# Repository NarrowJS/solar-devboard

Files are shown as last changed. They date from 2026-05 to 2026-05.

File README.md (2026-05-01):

## Solar Devboard
An ESP32 C6 mini based devboard that combines zigbee/wifi with solar and lipo charging to easily deploy remote sensing IOT devices.

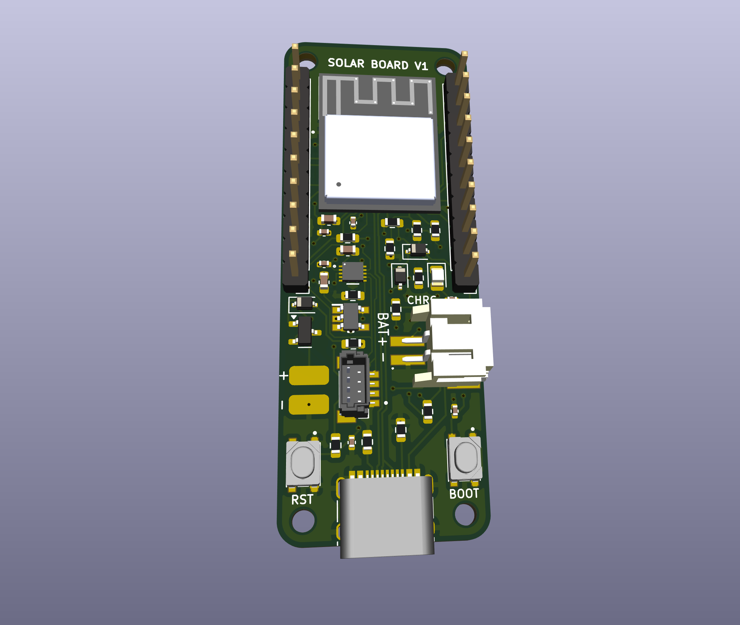
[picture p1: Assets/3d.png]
3d model

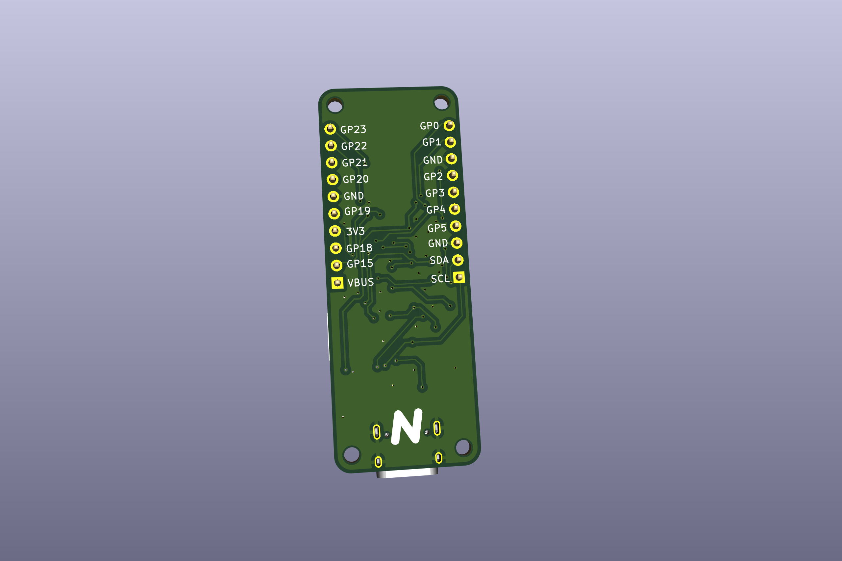
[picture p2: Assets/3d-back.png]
3d model back

## Features
- 3.7v Lipo charging circuit and JST connector
- Support for 3v - 18v solar panels
- Reverse polarity protection on solar panel connector
- ADC for lipo charge monitoring
- Power path for charging while on usb-c power
- Extremely compact form factor
- M2 mounting holes

## Why
- Solar panels are extremely useful for remote sensing applications to provide a power source without long wires or very large batteries
- Most solar projects require boost converters and extra breakout boards to connect lipo batteries safely
- Most solar charging boards are too large to be used in compact applications

## BOM
| Reference | Value | Datasheet | Footprint | Qty | DNP | Link |
|---|---|---|---|-----|-----|---|
| C1,C2,C4,C5,C10 | 100nF | ~ | Capacitor_SMD:C_0402_1005Metric | 5 | | https://www.lcsc.com/product-detail/C60474.html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 |
| C3,C6,C12 | 10uF | ~ | Capacitor_SMD:C_0603_1608Metric | 3 | | https://www.lcsc.com/product-detail/C19702.html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 |
| C7 | 1uF | ~ | Capacitor_SMD:C_0402_1005Metric | 1 | | https://www.lcsc.com/product-detail/C19702.html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 |
| D1 | CHARGE LED | ~ | LED_SMD:LED_0805_2012Metric | 1 | | https://www.lcsc.com/product-detail/C19702.html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 |
| D2,D3,D4 | 1N5819WS | https://datasheet.lcsc.com/lcsc/2204281430_Guangdong-Hottech-1N5819WS_C191023.pdf | Diode_SMD:D_SOD-323 | 3 | | https://www.lcsc.com/product-detail/C191023.html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 |
| IC1 | RT9080-33GJ5 | | RT9080-33GJ5:SOT94P280X100-5N | 1 | | https://www.lcsc.com/product-detail/C191023.html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 |
| J1 | USB_C_Receptacle_USB2.0_14P | https://www.usb.org/sites/default/files/documents/usb_type-c.zip | Connector_USB:USB_C_Receptacle_HRO_TYPE-C-31-M-12 | 1 | | https://www.lcsc.com/product-detail/C165948.html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 |
| J2 | SOLAR_IN + | ~ | Connector_Wire:SolderWirePad_1x01_SMD_1x2mm | 1 | | |
| J3 | SOLAR_IN - | ~ | Connector_Wire:SolderWirePad_1x01_SMD_1x2mm | 1 | | |
| J4,J5 | Conn_01x10_Pin | ~ | Connector_PinHeader_2.54mm:PinHeader_1x10_P2.54mm_Vertical | 2 | | https://www.lcsc.com/product-detail/C42431810.html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 |
| J6 | 4328 | | 4328:ADAFRUIT_4328 | 1 | | https://www.adafruit.com/product/4328 |
| P1 | S2B-PH-SM4-TB | | S2B-PH-SM4-TB:JST_S2B-PH-SM4-TB | 1 | | https://www.lcsc.com/product-detail/C295747.html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 |
| Q2 | AO3401A | http://www.aosmd.com/pdfs/datasheet/AO3401A.pdf | Package_TO_SOT_SMD:SOT-23 | 1 | | https://www.lcsc.com/product-detail/C15127.html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 |
| R1,R2 | 5k1 | ~ | Resistor_SMD:R_0603_1608Metric | 2 | | https://www.lcsc.com/product-detail/C15127.html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 |
| R3,R4,R5,R6,R8,R9,R10 | 10k | ~ | Resistor_SMD:R_0603_1608Metric | 7 | | https://www.lcsc.com/product-detail/C98220.html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 |
| R7 | 1k | ~ | Resistor_SMD:R_0603_1608Metric | 1 | | https://www.lcsc.com/product-detail/C2907002.html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 |
| R11 | 27k | ~ | Resistor_SMD:R_0603_1608Metric | 1 | | https://www.lcsc.com/product-detail/C22967.html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 |
| R12,R15 | 100k | ~ | Resistor_SMD:R_0603_1608Metric | 2 | | https://www.lcsc.com/product-detail/C14675.html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 |
| SW1,SW2 | PTS810_SJM_250_SMTR_LFS | | PTS810_SJM_250_SMTR_LFS:SW_PTS810_SJM_250_SMTR_LFS | 2 | | https://www.lcsc.com/product-detail/C116501.html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 |
| U1 | ESP32-C6-MINI-1-H4 | | ESP32-C6-MINI-1-H4:XCVR_ESP32-C6-MINI-1-H4 | 1 | | https://www.lcsc.com/product-detail/C5736265.html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 |
| U2 | PQ25186DLHR | https://www.ti.com/lit/gpn/bq25186 | BQ25186:WSON10_DLH_TEX | 1 | | https://www.lcsc.com/product-detail/C44639442.html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 |

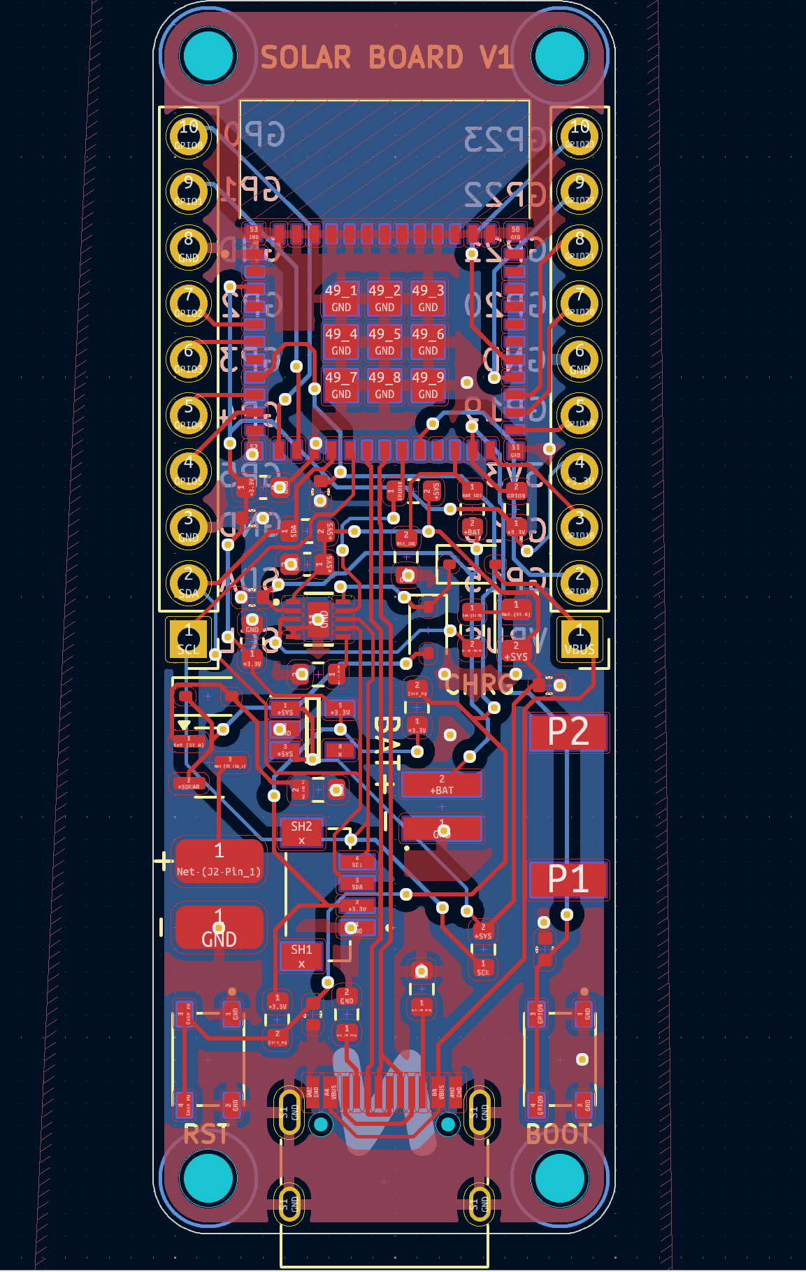
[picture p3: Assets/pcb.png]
pcb

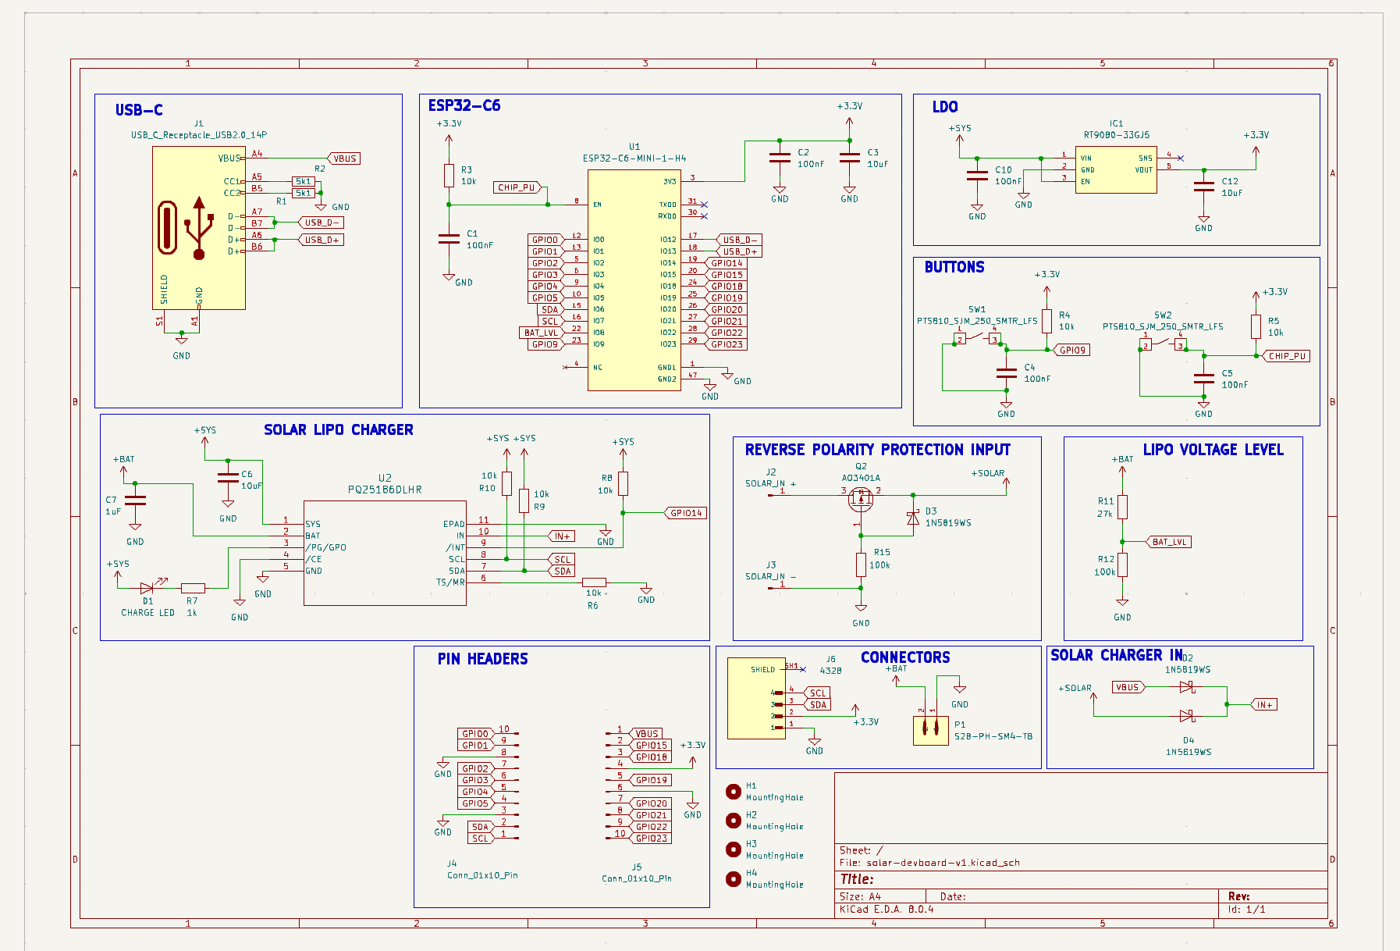
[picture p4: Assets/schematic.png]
schematic


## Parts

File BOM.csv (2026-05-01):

Reference | Value | Datasheet | Footprint | Qty | DNP | Link | total cost
C1,C2,C4,C5,C10 | 100nF | ~ | Capacitor_SMD:C_0402_1005Metric | 5 |  | https://www.lcsc.com/product-detail/C60474.html?s_z=n_q_100nF%25200402 | 0.11
C3,C6,C12 | 10uF | ~ | Capacitor_SMD:C_0603_1608Metric | 3 |  | https://www.lcsc.com/product-detail/C19702.html?s_z=n_q_10uF%25200603 | 0.4
C7 | 1uF | ~ | Capacitor_SMD:C_0402_1005Metric | 1 |  | https://www.lcsc.com/product-detail/C19702.html?s_z=n_q_10uF%25200603 | 0.28
D1 | CHARGE LED | ~ | LED_SMD:LED_0805_2012Metric | 1 |  | https://www.lcsc.com/product-detail/C19171391.html?s_z=n_q_red%2520led%2520smd%25200805 | 0.81
D2,D3,D4 | 1N5819WS | https://datasheet.lcsc.com/lcsc/2204281430_Guangdong-Hottech-1N5819WS_C191023.pdf | Diode_SMD:D_SOD-323 | 3 |  | https://www.lcsc.com/product-detail/C191023.html?s_z=n_q_1N5819WS | 0.56
IC1 | RT9080-33GJ5 |  | RT9080-33GJ5:SOT94P280X100-5N | 1 |  | https://www.lcsc.com/product-detail/C191023.html?s_z=n_q_1N5819WS | 0.58
J1 | USB_C_Receptacle_USB2.0_14P | https://www.usb.org/sites/default/files/documents/usb_type-c.zip | Connector_USB:USB_C_Receptacle_HRO_TYPE-C-31-M-12 | 1 |  | https://www.lcsc.com/product-detail/C165948.html?s_z=n_q_type%2520c | 0.93
J2 | SOLAR_IN + | ~ | Connector_Wire:SolderWirePad_1x01_SMD_1x2mm | 1 |  |  | 0
J3 | SOLAR_IN - | ~ | Connector_Wire:SolderWirePad_1x01_SMD_1x2mm | 1 |  |  | 0
J4,J5 | Conn_01x10_Pin | ~ | Connector_PinHeader_2.54mm:PinHeader_1x10_P2.54mm_Vertical | 2 |  | https://www.lcsc.com/product-detail/C42431810.html?s_z=n_q_pinheader%25201x10 | 0.52
J6 | 4328 |  | 4328:ADAFRUIT_4328 | 1 |  | https://www.adafruit.com/product/4328 | 3.95
P1 | S2B-PH-SM4-TB |  | S2B-PH-SM4-TB:JST_S2B-PH-SM4-TB | 1 |  | https://www.lcsc.com/product-detail/C295747.html?s_z=n_q_S2B-PH-SM4-TB | 0.97
Q2 | AO3401A | http://www.aosmd.com/pdfs/datasheet/AO3401A.pdf | Package_TO_SOT_SMD:SOT-23 | 1 |  | https://www.lcsc.com/product-detail/C15127.html?s_z=n_q_AO3401A | 0.59
R1,R2 | 5k1 | ~ | Resistor_SMD:R_0603_1608Metric | 2 |  | https://www.lcsc.com/product-detail/C15127.html?s_z=n_q_AO3401A | 0.12
R3,R4,R5,R6,R8,R9,R10 | 10k | ~ | Resistor_SMD:R_0603_1608Metric | 7 |  | https://www.lcsc.com/product-detail/C98220.html?s_z=n_q_10k%25200603 | 0.15
R7 | 1k | ~ | Resistor_SMD:R_0603_1608Metric | 1 |  | https://www.lcsc.com/product-detail/C2907002.html?s_z=n_q_1k%25200603 | 0.15
R11 | 27k | ~ | Resistor_SMD:R_0603_1608Metric | 1 |  | https://www.lcsc.com/product-detail/C22967.html?s_z=n_q_27k%25200603 | 0.16
R12,R15 | 100k | ~ | Resistor_SMD:R_0603_1608Metric | 2 |  | https://www.lcsc.com/product-detail/C14675.html?s_z=n_q_100k%25200603 | 0.14
SW1,SW2 | PTS810_SJM_250_SMTR_LFS |  | PTS810_SJM_250_SMTR_LFS:SW_PTS810_SJM_250_SMTR_LFS | 2 |  | https://www.lcsc.com/product-detail/C116501.html?s_z=n_q_PTS810_SJM_250_SMTR_LFS | 1.2
U1 | ESP32-C6-MINI-1-H4 |  | ESP32-C6-MINI-1-H4:XCVR_ESP32-C6-MINI-1-H4 | 1 |  | https://www.lcsc.com/product-detail/C5736265.html?s_z=n_q_esp32 | 3.99
U2 | PQ25186DLHR | https://www.ti.com/lit/gpn/bq25186 | BQ25186:WSON10_DLH_TEX | 1 |  | https://www.lcsc.com/product-detail/C44639442.html?s_z=n_q_PQ25186DLHR | 1.8

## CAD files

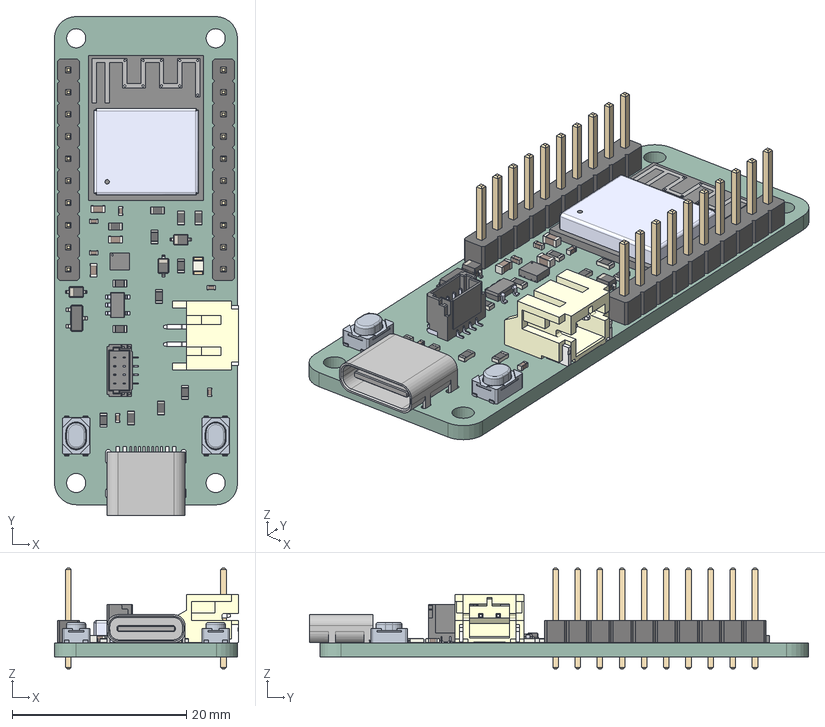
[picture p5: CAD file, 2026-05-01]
CAD/solar-devboard-v1.step
21.1 x 57.2 x 11.5 mm
C_0402_1005Metric x 6
PinHeader_1x10_P254mm_Vertical x 2
D_SOD_323 x 3
HRO TYPE-C-31-M-12 v4
R_0603_1608Metric x 13
C_0603_1608Metric x 3
BQ25185DLHR
ESP32-C3-MINI-1-N4
LED_0805_2012Metric
S2B-PH-SM4-TB(LF)(SN)
RT9080-xGJ
SOT_23
_autosave-solar-devboard-v1_PCB

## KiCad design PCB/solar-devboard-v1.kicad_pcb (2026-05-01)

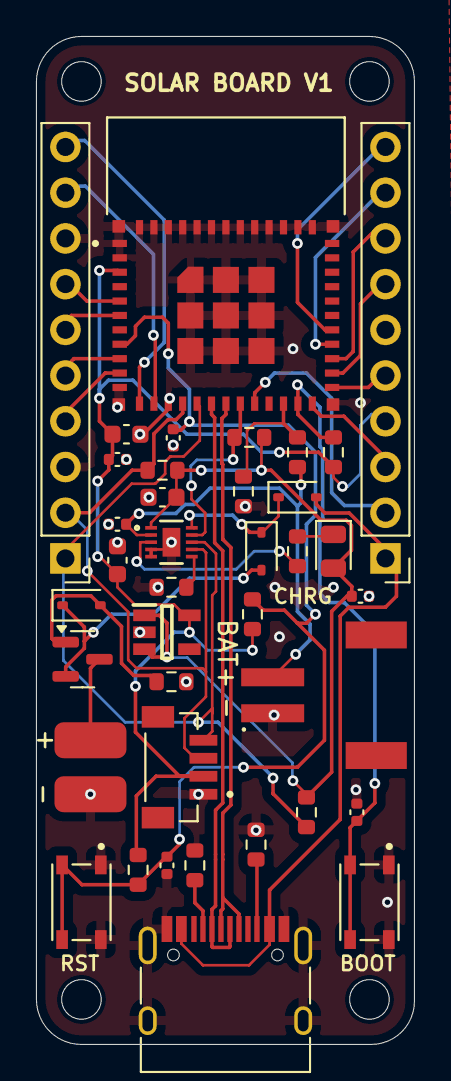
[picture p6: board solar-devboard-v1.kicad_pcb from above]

Board: 2 copper layers, 21.0 x 56.0 mm, 43 parts (0 on the bottom side), 35 nets.

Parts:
3-18V: SOLAR_IN +; SolderWirePad_1x01_SMD_1x2mm
BOOT: PTS810_SJM_250_SMTR_LFS; SW_PTS810_SJM_250_SMTR_LFS
C1, C2, C4, C5, C10: 100nF; C_0402_1005Metric
C3, C6, C12: 10uF; C_0603_1608Metric
C7: 1uF; C_0402_1005Metric
D1: CHARGE LED; LED_0805_2012Metric
D2, D3, D4: 1N5819WS; D_SOD-323
H1, H2, H3, H4: MountingHole; MountingHole_2.2mm_M2
IC1: RT9080-33GJ5; SOT94P280X100-5N
J1: USB_C_Receptacle_USB2.0_14P; USB_C_Receptacle_HRO_TYPE-C-31-M-12
J4, J5: Conn_01x10_Pin; PinHeader_1x10_P2.54mm_Vertical
J6: 4328; ADAFRUIT_4328
P1: S2B-PH-SM4-TB; JST_S2B-PH-SM4-TB
Q2: AO3401A; SOT-23
R1, R2: 5k1; R_0603_1608Metric
R3, R4, R5, R6, R8, R9, R10: 10k; R_0603_1608Metric
R7: 1k; R_0603_1608Metric
R11: 27k; R_0603_1608Metric
R12, R15: 100k; R_0603_1608Metric
RST: PTS810_SJM_250_SMTR_LFS; SW_PTS810_SJM_250_SMTR_LFS
U1: ESP32-C6-MINI-1-H4; XCVR_ESP32-C6-MINI-1-H4
U2: PQ25186DLHR; WSON10_DLH_TEX
_: SOLAR_IN -; SolderWirePad_1x01_SMD_1x2mm

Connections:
+3.3V: C2.1, C3.1, C12.1, IC1.5 (VOUT), J5.4, J6.2, R3.1, R4.1, R5.1, U1.3 (3V3)
+BAT: C7.1, P1.2, R11.2, U2.2 (BAT)
+SOLAR: D3.1 (K), D4.2 (A), Q2.2 (S)
+SYS: C6.1, C10.1, D1.2 (A), IC1.1 (VIN), IC1.3 (EN), R8.2, R9.2, R10.2, U2.1 (SYS)
BAT_LVL: R11.1, R12.2, U1.22 (IO8)
CHIP_PU: C1.1, C5.1, R3.2, R5.2, RST.3, RST.4, U1.8 (EN)
GND: BOOT.1, BOOT.2, C1.2, C2.2, C3.2, C4.2, C5.2, C6.2, C7.2, C10.2, C12.2, IC1.2 (GND), J1.A1 (GND), J1.A12 (GND), J1.B1 (GND), J1.B12 (GND), J1.S1 (SHIELD), J4.3, J4.8, J5.6, J6.1, P1.1, R1.2, R2.2, R6.2, R12.1, R15.1, RST.1, RST.2, U1.1 (GND1), U1.2 (GND1), U1.11 (GND1), U1.14 (GND1), U1.36 (GND1), U1.37 (GND1), U1.38 (GND1), U1.39 (GND1), U1.40 (GND1), U1.41 (GND1), U1.42 (GND1), U1.43 (GND1), U1.44 (GND1), U1.45 (GND1), U1.46 (GND1), U1.47 (GND2), U1.48 (GND2), U1.49_1 (GND2), U1.49_2 (GND2), U1.49_3 (GND2), U1.49_4 (GND2), U1.49_5 (GND2), U1.49_6 (GND2), U1.49_7 (GND2), U1.49_8 (GND2), U1.49_9 (GND2), U1.50 (GND2), U1.51 (GND2), U1.52 (GND2), U1.53 (GND2), U2.4 (/CE), U2.5 (GND), U2.11 (EPAD), _.1
GPIO0: J4.10, U1.12 (IO0)
GPIO1: J4.9, U1.13 (IO1)
GPIO2: J4.7, U1.5 (IO2)
GPIO3: J4.6, U1.6 (IO3)
GPIO4: J4.5, U1.9 (IO4)
GPIO5: J4.4, U1.10 (IO5)
GPIO9: BOOT.3, BOOT.4, C4.1, R4.2, U1.23 (IO9)
GPIO14: R8.1, U1.19 (IO14), U2.9 (/INT)
GPIO15: J5.2, U1.20 (IO15)
GPIO18: J5.3, U1.24 (IO18)
GPIO19: J5.5, U1.25 (IO19)
GPIO20: J5.7, U1.26 (IO20)
GPIO21: J5.8, U1.27 (IO21)
GPIO22: J5.9, U1.28 (IO22)
GPIO23: J5.10, U1.29 (IO23)
IN+: D2.1 (K), D4.1 (K), U2.10 (IN)
unnamed: D1.1 (K), R7.1
unnamed: D3.2 (A), Q2.1 (G), R15.2
unnamed: J1.A5 (CC1), R2.1
unnamed: J1.B5 (CC2), R1.1
unnamed: 3-18V.1, Q2.3 (D)
unnamed: R6.1, U2.6 (TS/MR)
unnamed: R7.2, U2.3 (/PG/GPO)
SCL: J4.1, J6.4, R10.1, U1.16 (IO7), U2.8 (SCL)
SDA: J4.2, J6.3, R9.1, U1.15 (IO6), U2.7 (SDA)
USB_D+: J1.A6 (D+), J1.B6 (D+), U1.18 (IO13)
USB_D-: J1.A7 (D-), J1.B7 (D-), U1.17 (IO12)
VBUS: D2.2 (A), J1.A4 (VBUS), J1.A9 (VBUS), J1.B4 (VBUS), J1.B9 (VBUS), J5.1

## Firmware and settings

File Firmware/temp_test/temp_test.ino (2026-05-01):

const int BAT_PIN = 8;
const int TEMP_PIN = 5;

void setup() {
  // put your setup code here, to run once:
  pinMode(BAT_PIN, INPUT);
  pinMode(TEMP_PIN, INPUT);
  Serial.begin(115200);

}

void loop() {
  // put your main code here, to run repeatedly:
  int bat_v = analogRead(BAT_PIN) * 4.2;
  Serial.println("Battery voltage: "+bat_v);

  int temp = analogRead(TEMP_PIN);
  Serial.println("Temperature: "+temp);

  delay(1000);
}

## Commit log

2026-05-01 Initialize README with project details and features
    Added detailed project description, features, and BOM link.
2026-05-01 Update README with detailed BOM and features
2026-05-01 Update README with reverse polarity protection feature
    Added reverse polarity protection to the solar panel connector in the features section.
2026-05-01 update bom price
    [BOM.csv]
2026-05-01 added temperature code in ino
